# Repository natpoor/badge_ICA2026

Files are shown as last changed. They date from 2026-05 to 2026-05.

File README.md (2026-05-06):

# badge_ICA2026
KiCAD etc files for the ICA 2026 PCB badge.
I am not entirely sure which files to place here, as I read some varying info on the web, so, best guess.

These files should get you a game-controller shaped blinking badge (four LEDs, colors/positions matching the Xbox controller), based on the ATMEGA 328PB chip. Has a Sleep button and a Mode button (to change blink patterns). Wants a 3v coin battery (2025/2032), and uses a connector off the programmer from Tag-Connect. Only has SMD components (so no THT on the back to catch on clothing, it's a badge to be worn). 

My coding is mostly Python and R scripts (linear), and I learned just before event-loop programming took hold, so my code works but I have been told it is a bit odd and there are better ways to do it. Next time!

Should have enough files for...

Badge - shape, art, components and layout (so the schematic, layout, and program files). 

BOM - Bill Of Materials (the parts to order).

Code - Arduino / C++ code (the .ino file). 

None of this would have happened without a lot of helpful people - posts to forums about schematics and code, sample working schematics (I copied the Arduino Uno schematic to start), some help from friends and relatives who know this material, and help from some people on the Arduino forum about the sleep code for the chip.

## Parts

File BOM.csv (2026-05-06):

Item # | Designator | Component | Quantity | Manufacturer | MPN | Description | Mount Type | Notes | Notes 2 | Datasheet
1 | R1 | 86.6 Ohm resistor | 1 | YAGEO | RC0805FR-0786R6L | RES 86.6 OHM 1% 1/8W 0805 | SMD | Specific manufacturer not important. Selected to work with specific LED's luminosity levels. | For Yellow LED. | https://www.yageogroup.com/content/datasheet/asset/file/PYU-RC_GROUP_51_ROHS_L
2 | R2 | 549 Ohm resistor | 1 | YAGEO | RC0805FR-07549RL | RES 549 OHM 1% 1/8W 0805 | SMD | Specific manufacturer not important. Selected to work with specific LED's luminosity levels. | For Red LED. | https://www.yageogroup.com/content/datasheet/asset/file/PYU-RC_GROUP_51_ROHS_L
3 | R3 | 178 Ohm resistor | 1 | YAGEO | RC0805FR-07178RL | RES 178 OHM 1% 1/8W 0805 | SMD | Specific manufacturer not important. Selected to work with specific LED's luminosity levels. | For Green LED. | https://www.yageogroup.com/content/datasheet/asset/file/PYU-RC_GROUP_51_ROHS_L
4 | R4 | 40.2 Ohm resistor | 1 | YAGEO | RC0805FR-0740R2L | RES 40.2 OHM 1% 1/8W 0805 | SMD | Specific manufacturer not important. Selected to work with specific LED's luminosity levels. | For Blue LED. | https://www.yageogroup.com/content/datasheet/asset/file/PYU-RC_GROUP_51_ROHS_L
5 | R5,R6 | 10k Ohm resistors | 2 | YAGEO | RC0805JR-0710KL | RES 10K OHM 5% 1/8W 0805 | SMD | Specific manufacturer not important. |  | https://calchip.com/wp-content/uploads/2025/05/RMSERIES-052225.pdf
6 | S1,S2 | Buttons | 2 | E-Switch | TL3300DF160Q | SWITCH TACTILE SPST-NO 0.05A 12V | SMD | Specific manufacturer not important. | Off-mom | https://configured-product-images.s3.amazonaws.com/Datasheets/TL3300.pdf
7 | LED1 | LED Yellow | 1 | Kingbright | AA3528LSYCKT/J3 | LED YELLOW CLEAR 2SMD | SMD | Specific manufacturer not important (as long as they work with the resistors). | 1.85V, 2mA | https://www.kingbrightusa.com/images/catalog/SPEC/AA3528LSYCKT-J3.pdf
8 | LED2 | LED Red | 1 | Kingbright | AA3528LSECKT/J3 | LED RED CLEAR 2SMD | SMD | Specific manufacturer not important (as long as they work with the resistors). | 1.8V, 2mA | https://www.kingbrightusa.com/images/catalog/SPEC/AA3528LSECKT-J3.pdf
9 | LED3 | LED Green | 1 | Kingbright | AA3528LZGCKT | LED GREEN CLEAR 2SMD | SMD | Specific manufacturer not important (as long as they work with the resistors). | 2.65V, 2mA | https://www.kingbrightusa.com/images/catalog/SPEC/AA3528LZGCKT.pdf
10 | LED4 | LED Blue | 1 | Kingbright | AA3528LVBS/D | LED BLUE CLEAR 2SMD | SMD | Specific manufacturer not important (as long as they work with the resistors). | 2.65V, 2mA | https://www.kingbrightusa.com/images/catalog/SPEC/AA3528LVBS-D.pdf
11 | U1 | ATMEGA 328PB | 1 | Microchip Technology | ATMEGA328PB-AU | IC MCU 8BIT 32KB FLASH 32TQFP | SMD | This is the important component (for programming). |  | https://ww1.microchip.com/downloads/en/DeviceDoc/40001907A.pdf
12 | C1 | Capacitor 0.1 µF | 1 | Murata Power Solutions Inc. | GCM21BR72A104KA37L | CAP CER 0.1UF 100V X7R 0805 | SMD | Specific manufacturer not important. |  | https://search.murata.co.jp/Ceramy/image/img/A01X/G101/ENG/GCJ188R71H104KA12-02B.pdf
13 | BT1 | Battery Holder | 1 | Adam Tech | BH-67D-5 | BATTERY RETAINER COIN 20MM SMD | SMD | Specific manufacturer not important. Please make sure the battery insertion side is facing up towards the near edge of the board, not down (because then the capacitor is in the way). Yes solder paste on the middle tab (I have tried to indicate this in the PCB but I think I have not done it correctly.) |  | https://app.adam-tech.com/products/download/data_sheet/196975/bh-67d-5-data-sheet.pdf
- | ICSP1 | Surface Pads | (1) | Tag Connect | (for the TC2030-IDC-NL) | Surface Pads and Holes (pads-only ICSP) | (DNP) | DNP | This is just the pads and holes on the PCB. No part to order. | https://www.tag-connect.com/wp-content/uploads/bsk-pdf-manager/2019/12/TC2030-IDC-NL-Datasheet-Rev-B.pdf

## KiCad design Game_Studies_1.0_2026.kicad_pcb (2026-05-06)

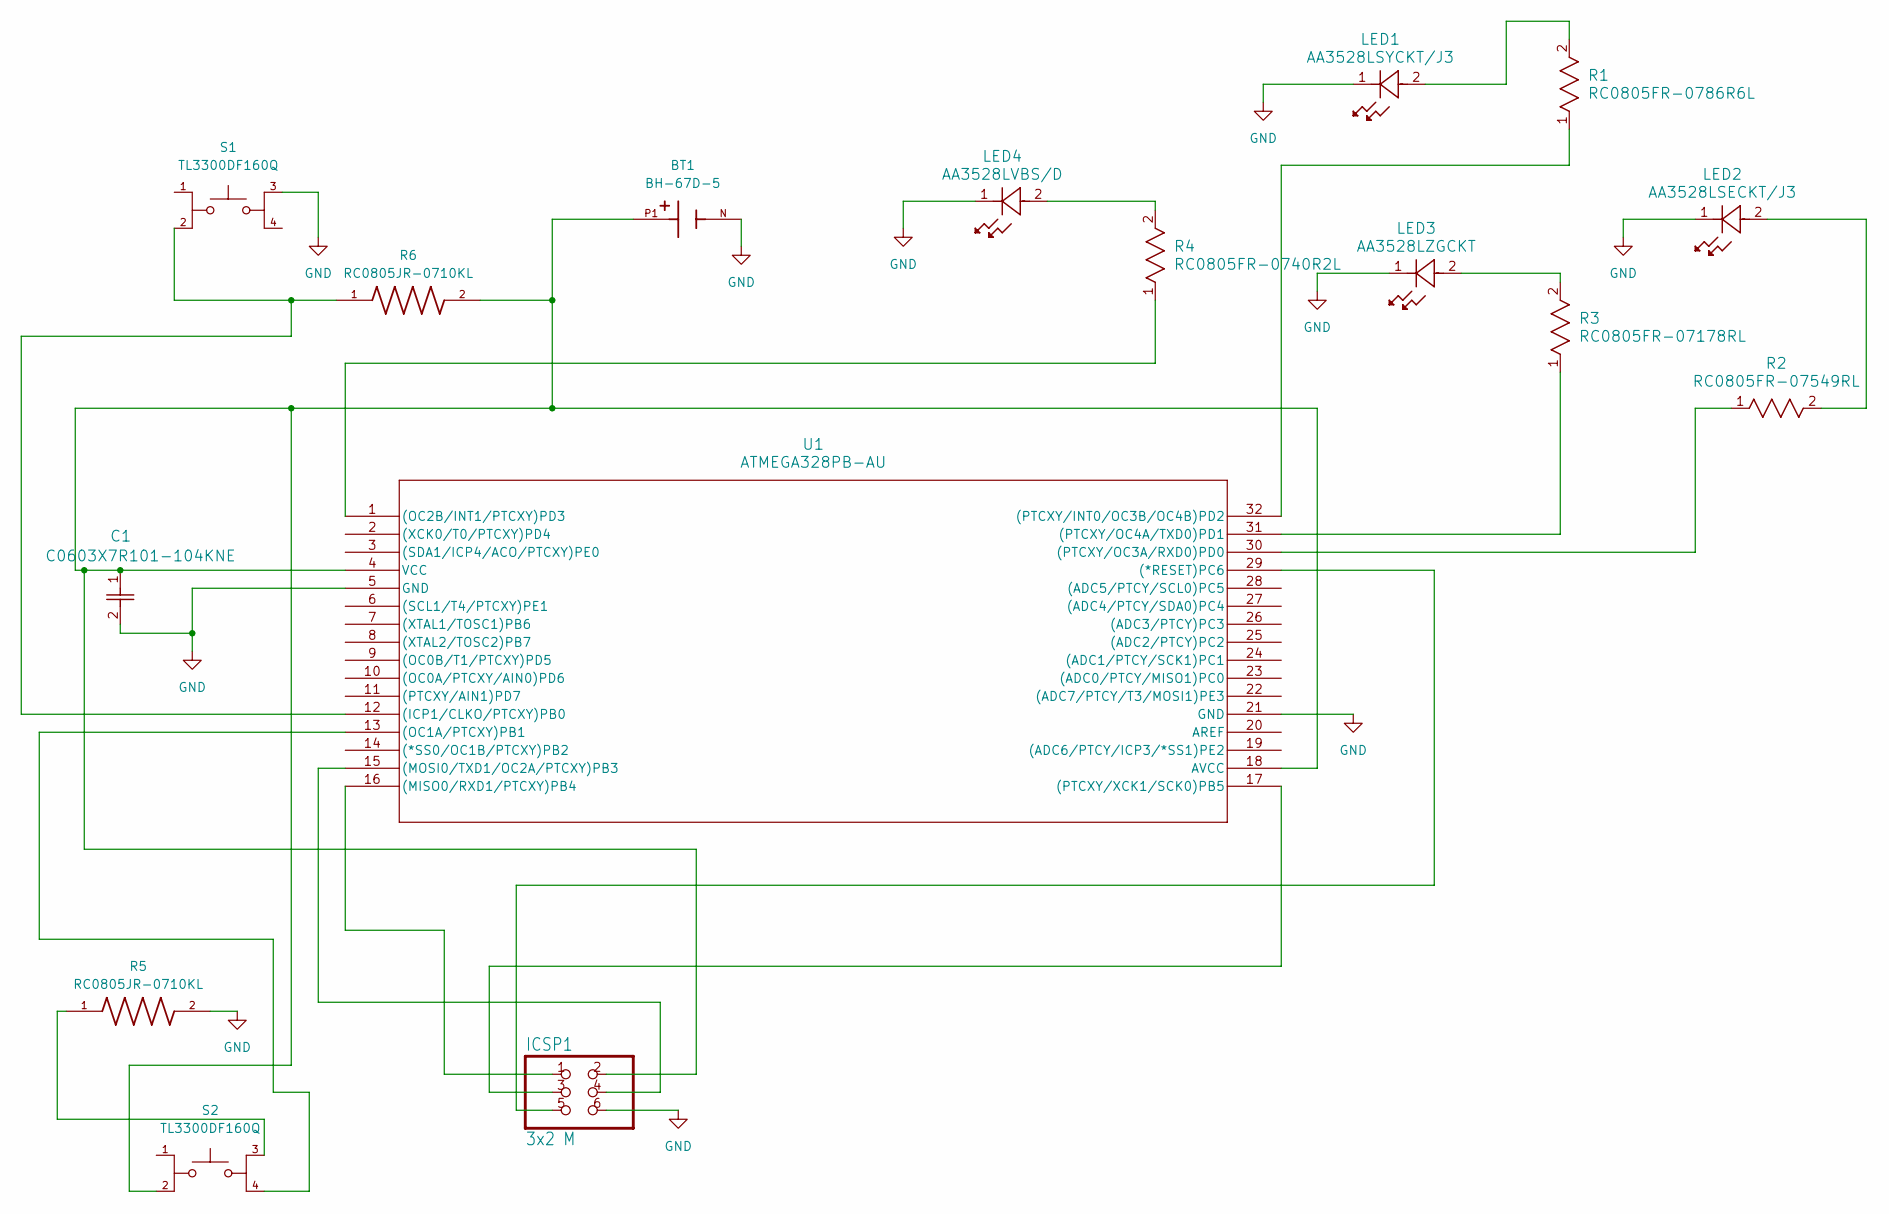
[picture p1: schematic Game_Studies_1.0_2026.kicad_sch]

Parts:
BT1: BH-67D-5; BAT_BH-67D-5; PARTREV A
C1: C0603X7R101-104KNE; CAP_C0603_VEN
ICSP1: 3x2 M; Conn_02x03_no_silk
LED1: AA3528LSYCKT/J3; Kingbright LED_AA3528LSYCKT&slash_J3
LED2: AA3528LSECKT/J3; Kingbright LED_AA3528LSECKT&slash_J3
LED3: AA3528LZGCKT; Kingbright LED_AA3528LZGCKT
LED4: AA3528LVBS/D; Kingbright LED_AA3528LVBS&slash_D
R1: RC0805FR-0786R6L; RC0805N_YAG
R2: RC0805FR-07549RL; RC0805N_YAG
R3: RC0805FR-07178RL; RC0805N_YAG
R4: RC0805FR-0740R2L; RC0805N_YAG
R5, R6: RC0805JR-0710KL; RESC2012X60N
S1, S2: TL3300DF160Q; SW_TL3300DF160Q; PARTREV A
U1: ATMEGA328PB-AU; 32A_MCH

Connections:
GND: BT1.N, C1.2, ICSP1.6, LED1.1, LED2.1, LED3.1, LED4.1, R5.2, S1.3, U1.5 (GND), U1.21 (GND); also elsewhere on the board
unnamed: LED1.2, R1.2
unnamed: LED2.2, R2.2
unnamed: LED3.2, R3.2
unnamed: LED4.2, R4.2
unnamed: R5.1, S2.3
unnamed: ICSP1.5, U1.29 ((*RESET)PC6)
unnamed: R6.1, S1.2, U1.12 ((ICP1/CLKO/PTCXY)PB0)
unnamed: ICSP1.1, U1.16 ((MISO0/RXD1/PTCXY)PB4)
unnamed: ICSP1.4, U1.15 ((MOSI0/TXD1/OC2A/PTCXY)PB3)
unnamed: S2.4, U1.13 ((OC1A/PTCXY)PB1)
unnamed: R4.1, U1.1 ((OC2B/INT1/PTCXY)PD3)
unnamed: R1.1, U1.32 ((PTCXY/INT0/OC3B/OC4B)PD2)
unnamed: R2.1, U1.30 ((PTCXY/OC3A/RXD0)PD0)
unnamed: R3.1, U1.31 ((PTCXY/OC4A/TXD0)PD1)
unnamed: ICSP1.3, U1.17 ((PTCXY/XCK1/SCK0)PB5)
unnamed 16: BT1.P1, C1.1, ICSP1.2, R6.2, S2.2, U1.4 (VCC), U1.18 (AVCC); also elsewhere on the board

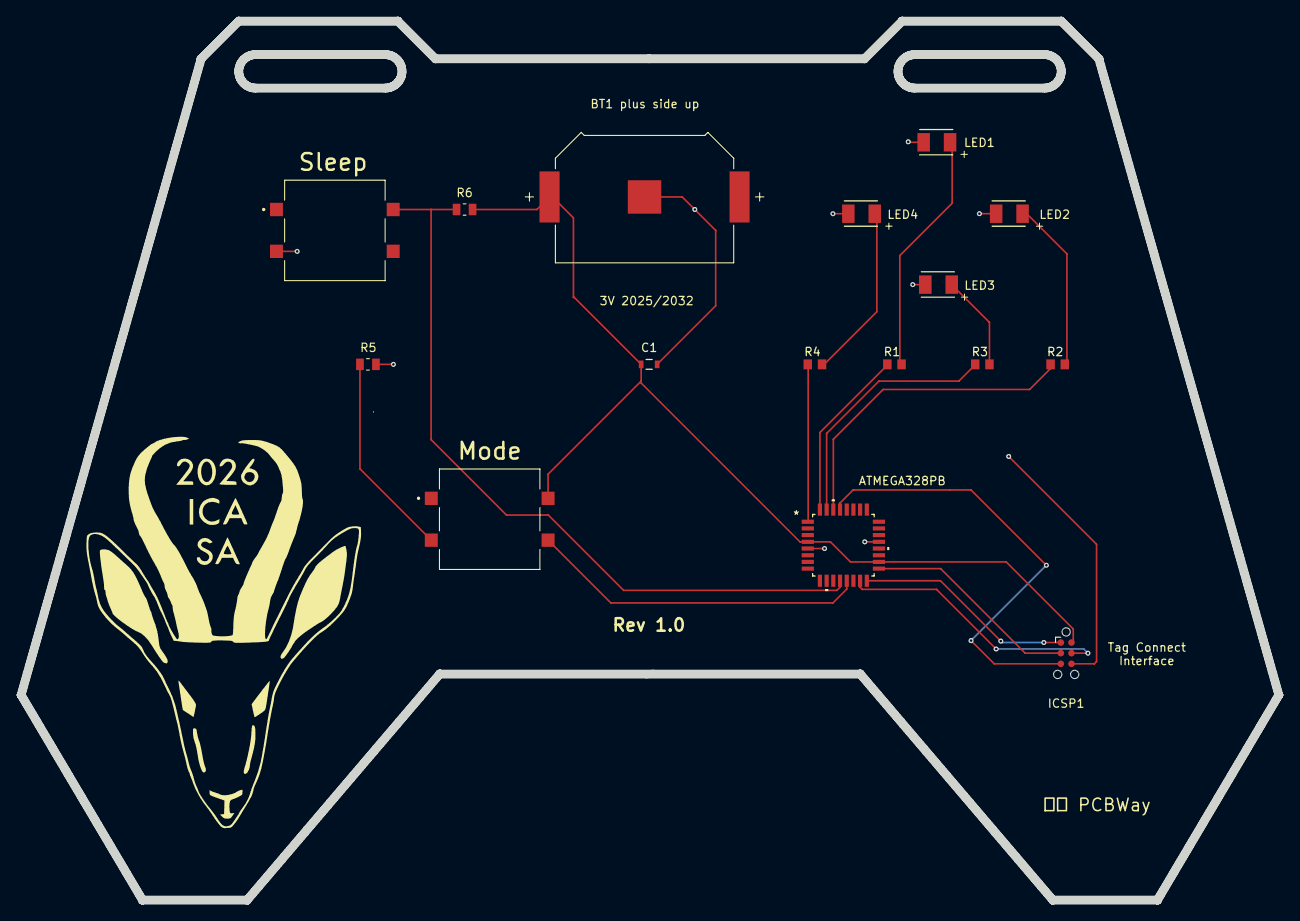
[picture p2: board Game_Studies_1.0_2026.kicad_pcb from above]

Board: 2 copper layers, 150.3 x 105.1 mm, 16 parts (0 on the bottom side), 17 nets.

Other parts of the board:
BT1 plus side up: BH-67D-5; BAT_BH-67D-5

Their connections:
GND: BT1 plus side up.N; also elsewhere on the board
unnamed 16: BT1 plus side up.P1; also elsewhere on the board

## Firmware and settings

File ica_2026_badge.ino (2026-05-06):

// For the ICA South Africa 2026 Conference Badge project.
// Xbox-like controller, with blinky LEDs where the controller buttons are.
// Summer / Fall 2025
// Sleep help from jim-p and alto777 (Arduino forum).

// Include Libraries
// For Sleep and Interrupt functionality.
#include <avr/sleep.h>
#include <avr/interrupt.h>


// Global Variables
// YRGB is the order of the lights, starting at noon and going clockwise (based on the buttons on an XBox 360 controller).
// SET PINS HERE (note difference between Arduino Metro board and custom board pin numbers).
// You can't use the simple pin numbers from the chip, you need to translate them since the Arduino IDE uses a different scheme.
// Here:  https://community.platformio.org/t/atmega328pb-arduino-pin-mappings/4248 
const int led_yellow = PD2; // ATMega328PB pin references.
const int led_red    = PD0;  
const int led_green  = PD1;  // Weird order due to circuit layout realities of the PCB and the ATMEGA328PB.
const int led_blue   = PD3;

// Different online schematics show different pin desginations. Beware!
const int button_onoff = 8; //12;  PB0  // Really is sleep, PULL UP RESISTOR (long story).
const int button_mode  = 9; //13;  PB1  // The mode button, PULL DOWN RESISTOR.

// Mode buttons setup here.
// https://docs.arduino.cc/built-in-examples/digital/StateChangeDetection/
int button_state = 0;  // Variable for reading the pushbutton status.
int button_prev  = 0;  // LOW. For the previous state of the button, helps get one click not a human-length hold/click.

// Pattern varaibles.
const int num_patterns = 13; // How many pattens do I have.
int pattern = 1; // 1 to num_patterns for # patterns of LED blinking. Will start at this pattern number. 

// The ISR SUPER IMPORTANT, MCU and schematic specific. 
ISR(PCINT0_vect) {
	PCICR &= ~_BV(PCIE0);  // Disable the PCINT[7:0] interrupts
}


void setup() {
  set_unused_pins(); // Set unused pins as inputs with pull-ups enabled (prevents floating pins from drawing current).

  pinMode(led_yellow, OUTPUT); // Set LED pins after setting unused pins, otherwise the LEDs are dim, I don't know why. 
  pinMode(led_red, OUTPUT);
  pinMode(led_green, OUTPUT);
  pinMode(led_blue, OUTPUT);
  // Ports B, C, D, and E all have internal resistors that can be set.
  pinMode(button_mode, INPUT);          // Build has a pulldown resistor on it.   
  pinMode(button_onoff, INPUT_PULLUP);  // INPUT_PULLUP if I set it like that, is that chip-internal? (I have a resistor on the board.)
      // Input pullups essentially set the default state of the pin to HIGH or 1, so that the pin is not affected by interference.
      // Do not need a resistor in this case. (I have one on the board.)

	set_sleep_mode(SLEEP_MODE_PWR_DOWN);  // Set sleep mode to full power down.

  init_off(); // Make sure all LEDs are set to LOW to start.
}

void loop() {
  if (pattern == 1)  blink();      // Starts on this one (unless changed above). 
  if (pattern == 2)  rotate();
  if (pattern == 3)  alternate(); 
  if (pattern == 4)  snake(); 
  if (pattern == 5)  rave();  
  if (pattern == 6)  random_slow(); 
  if (pattern == 7)  random_medium(); 
  if (pattern == 8)  random_fast(); 
  if (pattern == 9)  random_path();
  if (pattern == 10) bounce();
  if (pattern == 11) sideside(); 
  if (pattern == 12) fire(); 
  if (pattern == 13) fireworks();    // If you change these, change var num_patterns above.
} // main loop



// SLEEP FUNCTION hooray
void sleeper() {           // c/o jim-p (Arduino forum)
  bool yellow_on = (digitalRead(led_yellow) == HIGH);  // Have to reset the LEDs upon return from sleep.
  bool red_on    = (digitalRead(led_red) == HIGH);
  bool green_on  = (digitalRead(led_green) == HIGH);
  bool blue_on   = (digitalRead(led_blue) == HIGH);
  init_off();              // Turns all LEDs off, because it can catch them on at button press. 
	PCIFR = 0x07;            // Clear all the change on interrupt flags
	bitSet(PCICR, PCIE0);    // Enanble change interrupts on PCINT[7:0] pins
	bitSet(PCMSK0, PCINT0);  // Enable for PCINT0 (D8) This is the pin the button is connected to.
	interrupts();            // Make sure interrupts are enabled
	sleep_bod_disable();     // Disble BOD; saves power
  ADCSRA &= ~(1<<ADEN);    // Disable the ADC, must be re-endabled.
  ACSR |= (1 << ACD);      // Disable the analog comparator, must be re-endabled.
	sleep_mode();            // Enables sleep, puts cpu to sleep and disbles sleep when awoken

	// We are now ASLEEP, will stay here until interrupt occurs (the interrrupt that we just put on pin D8 with the "bitSet" lines just above).
	//ZZZZZZZZZZZZZZZZZZZZZZZZZZZZZZZZZZZZZZ
	// Now we are awake here because pin D8/PB0 got a signal.
  do {delay(20);}
    while (digitalRead(button_onoff) == LOW);     // Debounce, finger to get off the button. c/o alto777 (Arduino forum)
  ADCSRA |= (1<<ADEN);                            // Re-enables the ADC.
  ACSR |= (0 << ACD);                             // Re-enables the analog comparator.
  if (yellow_on) digitalWrite(led_yellow, HIGH);  // Set the LEDs back to where they were (matters for some patterns).
  if (red_on) digitalWrite(led_red, HIGH);
  if (green_on) digitalWrite(led_green, HIGH);
  if (blue_on) digitalWrite(led_blue, HIGH);
}


void set_unused_pins() {
  // Set unused pins as inputs with pull-ups enabled (prevents floating pins from drawing current).
  // The pins here are never used in this design (ICA SA 2026 XBOX badge).
  // Top and Right side of 328PB
  pinMode(PC5, INPUT_PULLUP); // 28
  pinMode(PC4, INPUT_PULLUP); // 27
  pinMode(PC3, INPUT_PULLUP); // 26
  pinMode(PC2, INPUT_PULLUP); // 25
  pinMode(PC1, INPUT_PULLUP); // 24
  pinMode(PC0, INPUT_PULLUP); // 23
  pinMode(PE3, INPUT_PULLUP); // 22
  pinMode(PE2, INPUT_PULLUP); // 19

  // Bottom of 328PB
  pinMode(PD5, INPUT_PULLUP); //  9
  pinMode(PD6, INPUT_PULLUP); // 10
  pinMode(PD7, INPUT_PULLUP); // 11
  pinMode(PB2, INPUT_PULLUP); // 14

  // Left side of 328PB
  pinMode(PD4, INPUT_PULLUP); // 2
  pinMode(PE0, INPUT_PULLUP); // 3
  pinMode(PE1, INPUT_PULLUP); // 6
  pinMode(PB6, INPUT_PULLUP); // 7
  pinMode(PB7, INPUT_PULLUP); // 8
}


// SECONDARY FUNCTIONS (these assist the main pattern functions).

// Helper functions that set LEDs to various states.
void init_off() { 
  digitalWrite(led_yellow, LOW);
  digitalWrite(led_red, LOW);
  digitalWrite(led_green, LOW);
  digitalWrite(led_blue, LOW);
}
void init_on() {
  digitalWrite(led_yellow, HIGH);
  digitalWrite(led_red, HIGH);
  digitalWrite(led_green, HIGH);
  digitalWrite(led_blue, HIGH);
}

// For the mode/pattern button, which pattern by number.
void increment() {
  pattern++; // Pattern is a global var so it is just set, not returned.
  if (pattern > num_patterns) pattern = 1;
  init_off(); // Because if you're in this function, the mode button was pushed, so start new pattern.
  delay(70); // Perhaps avoid bounce?
}

// If the LEDs are on turn them off and vice-versa, for the blink pattern.
void reverse_all() {
  if (digitalRead(led_red) == HIGH) init_off(); // If one is on, they are all on, turn all off.
  else init_on();
} // reverse_all

// These two are used by the rave function, if off, turn it on and return an "on until" time, etc. 
unsigned long rave_on(int which_led){
  digitalWrite(which_led, HIGH);
  unsigned long on_until = millis() + random(5, 50);  // times adjusted
  return on_until;
}
unsigned long rave_off(int which_led) {
  digitalWrite(which_led, LOW); 
  unsigned long off_until = millis() + random(5, 50);
  return off_until;
}

// All of these four turn one on and make sure the others are off.
void yellow_only() {
  digitalWrite(led_yellow, HIGH);
  digitalWrite(led_red, LOW);
  digitalWrite(led_green, LOW);
  digitalWrite(led_blue, LOW);
}
void red_only() {
  digitalWrite(led_yellow, LOW);
  digitalWrite(led_red, HIGH);
  digitalWrite(led_green, LOW);
  digitalWrite(led_blue, LOW);
}
void green_only() {
  digitalWrite(led_yellow, LOW);
  digitalWrite(led_red, LOW);
  digitalWrite(led_green, HIGH);
  digitalWrite(led_blue, LOW);
}
void blue_only() {
  digitalWrite(led_yellow, LOW);
  digitalWrite(led_red, LOW);
  digitalWrite(led_green, LOW);
  digitalWrite(led_blue, HIGH);
}

// Gamma Correction Function (for fading the LEDs).
int gamma_correct(int uncorrected_level) {
  // Convert 0-255 to 0.0-1.0 .
  float decimal_level = uncorrected_level / 255.0; // "If doing math with floats, you need to add a decimal point, otherwise it will be treated as an int."  = 0
  // Gamma adjust.
  float corrected_decimal = decimal_level * decimal_level * decimal_level;
  // Convert back to 0-255 metric and return it.
  return corrected_decimal * 255;
}


// PRIMARY FUNCTIONS these are the patterns (they may call a seconadry function for common actions).

void blink() {
  unsigned long start = millis();
  unsigned long now;
  init_on();

  while (true) {
    if (digitalRead(button_onoff) == LOW) {     // if on/off button press, do sleep function call
      do {delay(20);}
        while (digitalRead(button_onoff) == LOW); 
      sleeper();
    }
    now = millis();
    button_prev = button_state; 
    button_state = digitalRead(button_mode);
    if (button_state == HIGH && button_prev == LOW) { // signal from mode button
      increment();
      return; // break out of the function
    }
    if (now - start >= 30) {   // beta timing for board
      reverse_all();  //
      start = millis();
    }
  } // while
} // blink


void rotate() {
  unsigned long now = millis();
  unsigned long y_off = now + 45;
  unsigned long r_off = now + 90;
  unsigned long g_off = now + 135;
  unsigned long b_off = now + 180;

  digitalWrite(led_yellow, HIGH);

  while (true) {
    if (digitalRead(button_onoff) == LOW) {     // if on/off button press, do sleep function call
      do {delay(20);}
        while (digitalRead(button_onoff) == LOW); 
      sleeper();
    }
    now = millis();
    button_prev = button_state; 
    button_state = digitalRead(button_mode);
    if (button_state == HIGH && button_prev == LOW) { // signal from mode button
      increment();
      return; // break out of the function
    }

    if (now >= y_off) {
      digitalWrite(led_yellow, LOW);
      digitalWrite(led_red, HIGH);
      y_off = now + 180;
      r_off = now + 45;
    } 
    else if (now >= r_off) {
      digitalWrite(led_red, LOW);
      digitalWrite(led_green, HIGH);
      r_off = now + 180;
      g_off = now + 45;
    }
    else if (now >= g_off) {
      digitalWrite(led_green, LOW);
      digitalWrite(led_blue, HIGH);
      g_off = now + 180;
      b_off = now + 45;
    }
    else if (now >= b_off) {
      digitalWrite(led_blue, LOW);
      digitalWrite(led_yellow, HIGH);
      b_off = now + 180;
      y_off = now + 45;
    }   
  } // while
} // rotate


void alternate() {
  // Up and down, then left and right.
  const int alternate_delay = 50; // The millis delay for this function.  Changed for PCB.
  unsigned long ud_on = millis();  // Up Down when it has turned on.
  unsigned long lr_on = ud_on + alternate_delay; // Left Right on.
  unsigned long now;

  digitalWrite(led_yellow, HIGH);
  digitalWrite(led_green, HIGH);
  digitalWrite(led_red, LOW);
  digitalWrite(led_blue, LOW);

  while (true) {
    if (digitalRead(button_onoff) == LOW) {     // if on/off button press, do sleep function call
      do {delay(20);}
        while (digitalRead(button_onoff) == LOW); 
      sleeper();
    }
    now = millis();
    button_prev = button_state; 
    button_state = digitalRead(button_mode);
    if (button_state == HIGH && button_prev == LOW) { // signal from mode button
      increment();
      return; // break out of the function
    }
    if (now - ud_on >= alternate_delay) {
      digitalWrite(led_yellow, LOW);
      digitalWrite(led_green, LOW);
      digitalWrite(led_red, HIGH);
      digitalWrite(led_blue, HIGH);
      ud_on = lr_on + alternate_delay; // e.g., 50 + 50
    }
    else if (now - lr_on >= alternate_delay) {
      digitalWrite(led_yellow, HIGH);
      digitalWrite(led_green, HIGH);
      digitalWrite(led_red, LOW);
      digitalWrite(led_blue, LOW);
      lr_on = ud_on + alternate_delay;
    }
  } // while
} // alternate


void snake() {
  // Grows and then shrinks    YRGB
  const int on_for    = 125;  // Times adjusted for PCB. 
  const int end_pause = 125;  // Pause before restarting the snake loop.

  unsigned long y_on  =  0;
  unsigned long r_on  = 25;
  unsigned long g_on  = 50;
  unsigned long b_on  = 75;
  unsigned long y_off = y_on + on_for;
  unsigned long r_off = r_on + on_for;
  unsigned long g_off = g_on + on_for;
  unsigned long b_off = b_on + on_for;
  unsigned long now   =  0; // This was why the start pattern was wonky.
  unsigned long start = millis();

  while (true) {
    if (digitalRead(button_onoff) == LOW) {     // if on/off button press, do sleep function call
      do {delay(20);}
        while (digitalRead(button_onoff) == LOW); 
      sleeper();
    }
    button_prev = button_state; 
    button_state = digitalRead(button_mode);
    if (button_state == HIGH && button_prev == LOW) { // signal from mode button
      increment();
      return; // break out of the function
    }
    if (now >= y_on) {
      digitalWrite(led_yellow, HIGH);
      y_on = y_off + end_pause;
    }
    if (now >= r_on) {
      digitalWrite(led_red, HIGH);
      r_on = r_off + end_pause;
    }
    if (now >= g_on) {
      digitalWrite(led_green, HIGH);
      g_on = g_off + end_pause;
    }
    if (now >= b_on) {
      digitalWrite(led_blue, HIGH);
      b_on = b_off + end_pause;
    }
    if (now > y_off) {
      digitalWrite(led_yellow, LOW);
      y_off = y_on + on_for;
    }
    if (now > r_off) {
      digitalWrite(led_red, LOW);
      r_off = r_on + on_for;
    }
    if (now > g_off) {
      digitalWrite(led_green, LOW);
      g_off = g_on + on_for;
    }
    if (now > b_off) {
      digitalWrite(led_blue, LOW);
      b_off = b_on + on_for;
    }
    now = millis() - start; // Should time the function and add it to the "now".
  } // while
} // snake


void rave() {
  // This is random on all of them: random(min, max+1).
  unsigned long yellow_on_until  = 0;
  unsigned long yellow_off_until = 0;
  unsigned long red_on_until     = 0;
  unsigned long red_off_until    = 0;
  unsigned long green_on_until   = 0;
  unsigned long green_off_until  = 0;
  unsigned long blue_on_until    = 0;
  unsigned long blue_off_until   = 0;
  unsigned long now = 0;

  // Start all on with random rave on values.
  yellow_on_until = rave_on(led_yellow);
  red_on_until = rave_on(led_red);
  green_on_until = rave_on(led_green);
  blue_on_until = rave_on(led_blue);

  while (true) {
    if (digitalRead(button_onoff) == LOW) {     // if on/off button press, do sleep function call
      do {delay(20);}
        while (digitalRead(button_onoff) == LOW); 
      sleeper();
    }
    now = millis();
    button_prev = button_state; 
    button_state = digitalRead(button_mode);
    if (button_state == HIGH && button_prev == LOW) { // signal from mode button
      increment();
      return; // break out of the function
    }
    // If on, should it be turned off? If off, should it be turned on?
    if (digitalRead(led_yellow) == HIGH) { if (now > yellow_on_until) yellow_off_until = rave_off(led_yellow); }
    else { if (now > yellow_off_until) yellow_on_until = rave_on(led_yellow); }

    if (digitalRead(led_red) == HIGH) { if (now > red_on_until) red_off_until = rave_off(led_red); }
    else { if (now > red_off_until) red_on_until = rave_on(led_red);  }

    if (digitalRead(led_green) == HIGH) { if (now > green_on_until) green_off_until = rave_off(led_green); }
    else { if (now > green_off_until) green_on_until = rave_on(led_green); }

    if (digitalRead(led_blue) == HIGH) { if (now > blue_on_until) blue_off_until = rave_off(led_blue); }
    else { if (now > blue_off_until) blue_on_until = rave_on(led_blue); }

  } // while
} // rave function


void random_slow() {
  unsigned long pause = 35;
  rando(pause);
}

void random_medium() {
  unsigned long pause = 21;
  rando(pause);
}

void random_fast() {
  unsigned long pause = 7;
  rando(pause);
}

void rando(unsigned long pause) {
  int prev   = 0;
  int prev_2 = 0;
  
  unsigned long now   = 0;
  unsigned long start = millis();

  while (true) {
    if (digitalRead(button_onoff) == LOW) {     // if on/off button press, do sleep function call
      do {delay(20);}
        while (digitalRead(button_onoff) == LOW); 
      sleeper();
    }
    now = millis();
    button_prev = button_state; 
    button_state = digitalRead(button_mode);
    if (button_state == HIGH && button_prev == LOW) { // signal from mode button
      increment();
      return; // break out of the function
    }
    if (now - start >= pause) {
      start = millis();
      int roll = random(1,5); // Gives it a value so you can compare on next line.
      while (roll == prev_2) {roll = random(1,5);} // Reroll -- allows for 1 match but not more than that.
      prev_2 = prev; // Okay passed, so update these two.
      prev = roll;
      if (roll == 1) {
        yellow_only();
      }
      else if (roll == 2) {
        red_only();
      }
      else if (roll == 3) {
        green_only();
      }
      else if (roll == 4) {
        blue_only();
      }
    } // if now - start
  } // while true
} // rando


void random_path() {
  // Random, but only activates a neighbor (a "path"). 
  unsigned long last = 0;
  unsigned long now = 0; 
  const int pause = 40;           // adjusted for PCB
  int which = 1; // 1y 2r 3g 4b
  int upit = 0; // Int read as Boolean, random, "up it" up the value or not, beware wrap 1-4.

  digitalWrite(led_yellow, HIGH);
  last = millis();

  while (true) {
    if (digitalRead(button_onoff) == LOW) {     // if on/off button press, do sleep function call
      do {delay(20);}
        while (digitalRead(button_onoff) == LOW); 
      sleeper();
    }
    now = millis();
    button_prev = button_state; 
    button_state = digitalRead(button_mode);
    if (button_state == HIGH && button_prev == LOW) { // signal from mode button
      increment();
      return; // break out of the function
    }
    if (now - last >= pause) {   // Time to move it one.
      // First get the new LED number.
      upit = random(0,2); // Returns 0,1 can be read as Boolean.
      last = millis(); // Update that.
      if (upit) {
        which++;
        if (which > 4) which = 1;
      }
      else { // Else don't up-it, lower it 1-4.
        which--;
        if (which < 1) which = 4;
      }
      if (which == 1) yellow_only();
      else if (which == 2) red_only();
      else if (which == 3) green_only();
      else blue_only();
    } // if time to move it one

  } // while true
} // random_path


void bounce() { // 1, then 2&4, then 3, then 2&4, then 1, etc
  // Similar to sideside function.
  int which_step = 1; // Which step of the pattern, so which is on and which is next (1, 2, 3, 4).
  unsigned long now = 0;
  unsigned long last = millis();
  const int pause = 33;  // adjusted

  yellow_only(); // start

  while (true) {
    if (digitalRead(button_onoff) == LOW) {     // if on/off button press, do sleep function call
      do {delay(20);}
        while (digitalRead(button_onoff) == LOW); 
      sleeper();
    }
    now = millis();
    button_prev = button_state; 
    button_state = digitalRead(button_mode);
    if (button_state == HIGH && button_prev == LOW) { // signal from mode button
      increment();
      return; // break out of the function
    }
    if (now - last >= pause) {
      last = millis();
      which_step++;
      if (which_step > 4) which_step = 1;
      if      (which_step == 1) yellow_only();
      else if (which_step == 2) {digitalWrite(led_red, HIGH); digitalWrite(led_blue, HIGH); digitalWrite(led_yellow, LOW);}
      else if (which_step == 3) green_only();
      else if (which_step == 4) {digitalWrite(led_red, HIGH); digitalWrite(led_blue, HIGH); digitalWrite(led_green, LOW);}
    }
  } // while true
} // bounce


void sideside() { // u, r, d, r, u, l, d, l, u, etc, 1 2 3 4 for position, do where in pattern?
  int which_step = 1; // Which step of the pattern, so which is on and which is next.
    // 1u 2r 3d 4r 5u 6l 7d 8l 9u that is the start again so 1-8.
  unsigned long now = 0;
  unsigned long last = millis();
  const int pause = 33;  // adjusted

  yellow_only(); // start

  while (true) {
    if (digitalRead(button_onoff) == LOW) {     // if on/off button press, do sleep function call
      do {delay(20);}
        while (digitalRead(button_onoff) == LOW); 
      sleeper();
    }
    now = millis();
    button_prev = button_state; 
    button_state = digitalRead(button_mode);
    if (button_state == HIGH && button_prev == LOW) { // signal from mode button
      increment();
      return; // break out of the function
    }
    if (now - last >= pause) {
      last = millis();
      which_step++;
      if (which_step > 8) which_step = 1;
      if      (which_step == 1) yellow_only();
      else if (which_step == 2) red_only();
      else if (which_step == 3) green_only();
      else if (which_step == 4) red_only();
      else if (which_step == 5) yellow_only();
      else if (which_step == 6) blue_only();
      else if (which_step == 7) green_only();
      else if (which_step == 8) blue_only();
    }
  } // while true
} // sideside
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
